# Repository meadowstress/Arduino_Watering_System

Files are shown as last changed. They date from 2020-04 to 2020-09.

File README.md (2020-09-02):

# Arduino_Watering_System

This repo was created for my own plant watering system on my balcony. The project has basically reached the development peak.
With the current ressources of an Arduino Uno further feature development is pretty limited. So in the future activities will
be limited. And if time allows I will spend my energy in better unit tests and refactoring work.

You'll find the website of this repository here: https://meadowstress.github.io/Arduino_Watering_System/

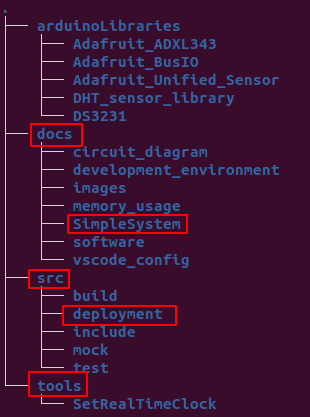
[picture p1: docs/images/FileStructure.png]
FileStructure


There are several folders in the repo. The most interesting for others is possibly the "src/deployment" folder. You can have a
look at the Arduino entry point in the "deployment.ino". All self written libraries are within the "deployment" folder.

If you want to recreate my plant watering system or parts of it you can have a look at the "doc" folder. In "circuit_diagram"
you find a Fritzing diagramm of my system. In "software" you'll find some useful tipps on how to handle the code.

If you just want to get started with programming an Arduino you'll find in docs/SimpleSystem a simplistic apporach including
system code and circuit diagramm to get started with an basic Arduino watering system.

All other folders are used for developing this project further and are possibly of minor interest to you:
The folder "src" contains the development code of my project including all unit tests. I use this folder to develop Arduino
code on my PC in order to speed up development. In "tools" you find scripts which are necessary in order to configure used
hardware parts.

## Overview

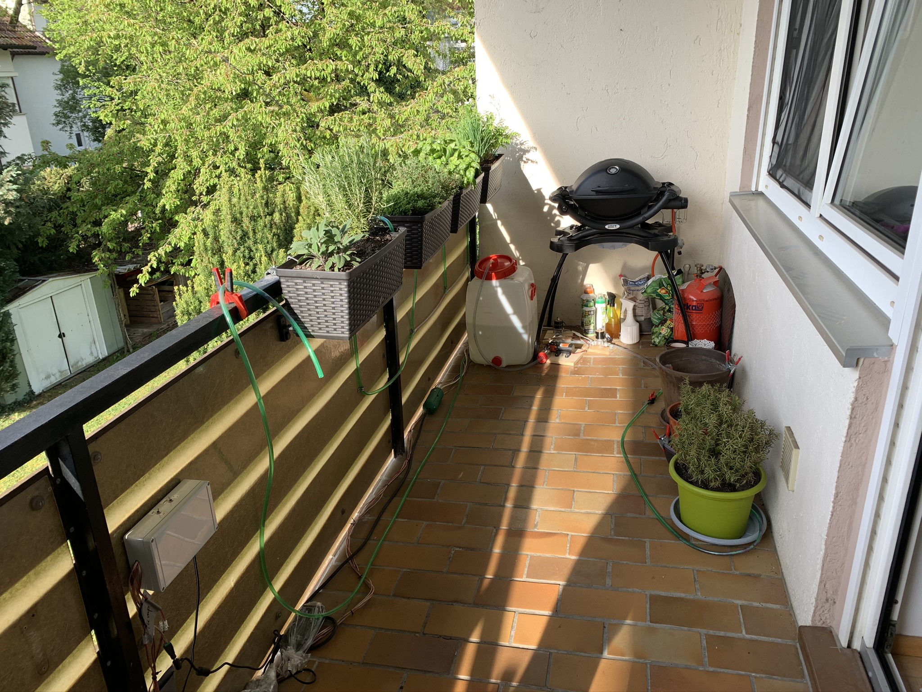
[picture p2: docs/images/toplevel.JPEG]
toplevel


### Control Box

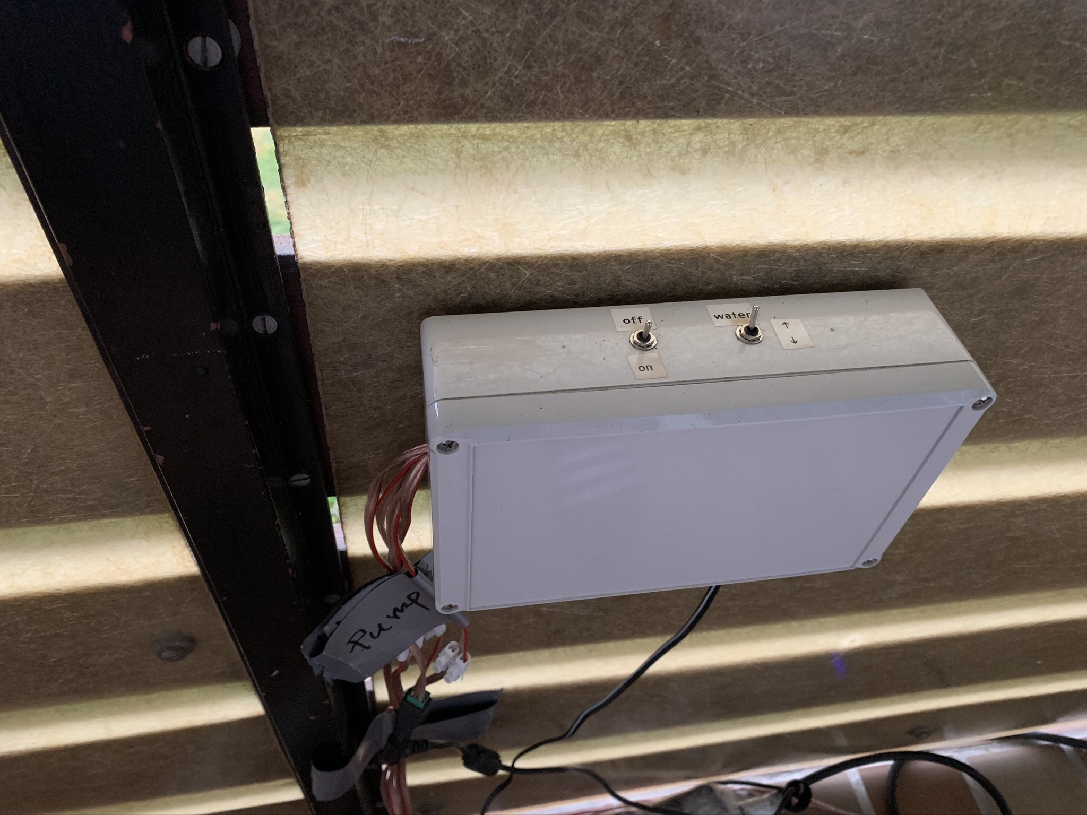
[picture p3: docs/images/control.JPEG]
control


## Pump and Valves

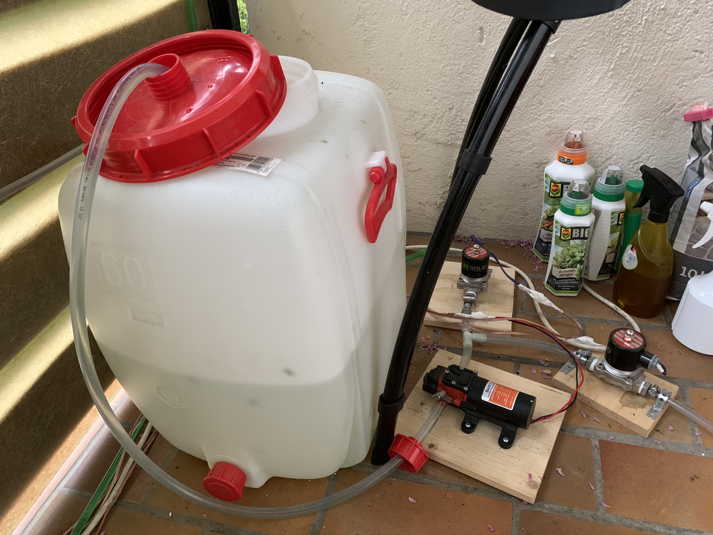
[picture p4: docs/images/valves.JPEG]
valves


## Tubes to top Plants

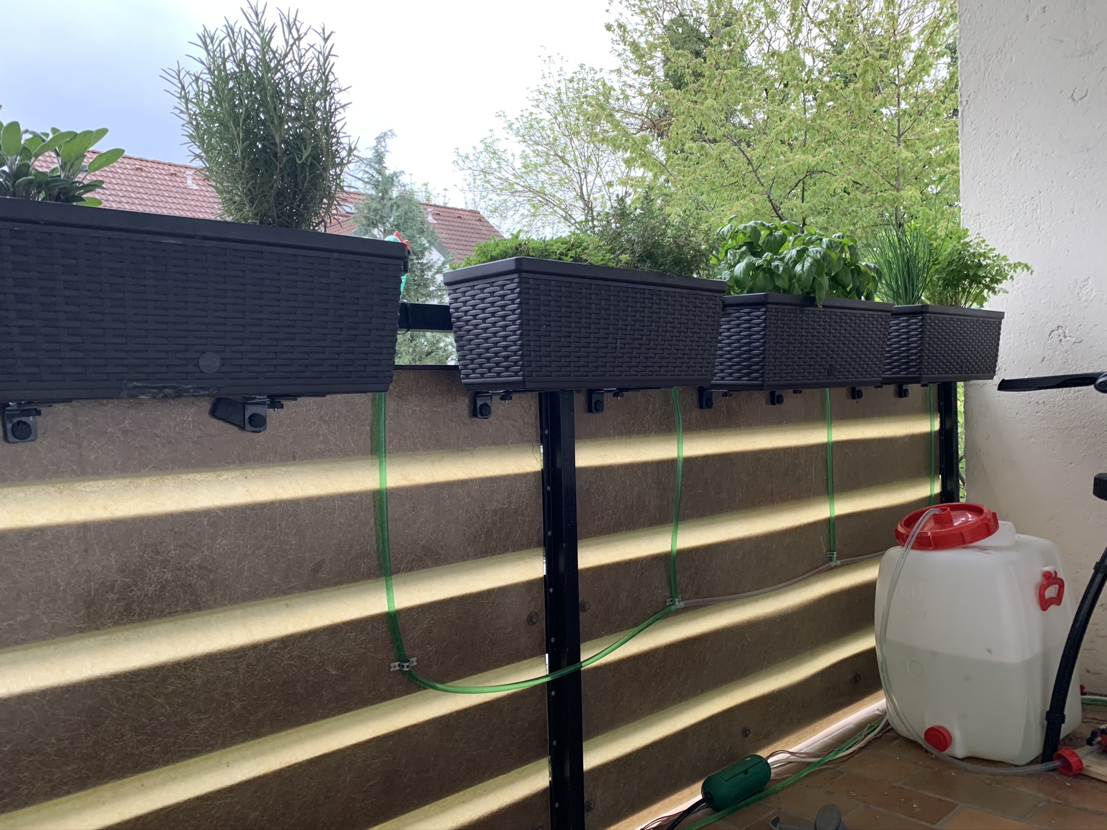
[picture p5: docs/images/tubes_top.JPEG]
tubes_top


## Tubes to bottom Plants

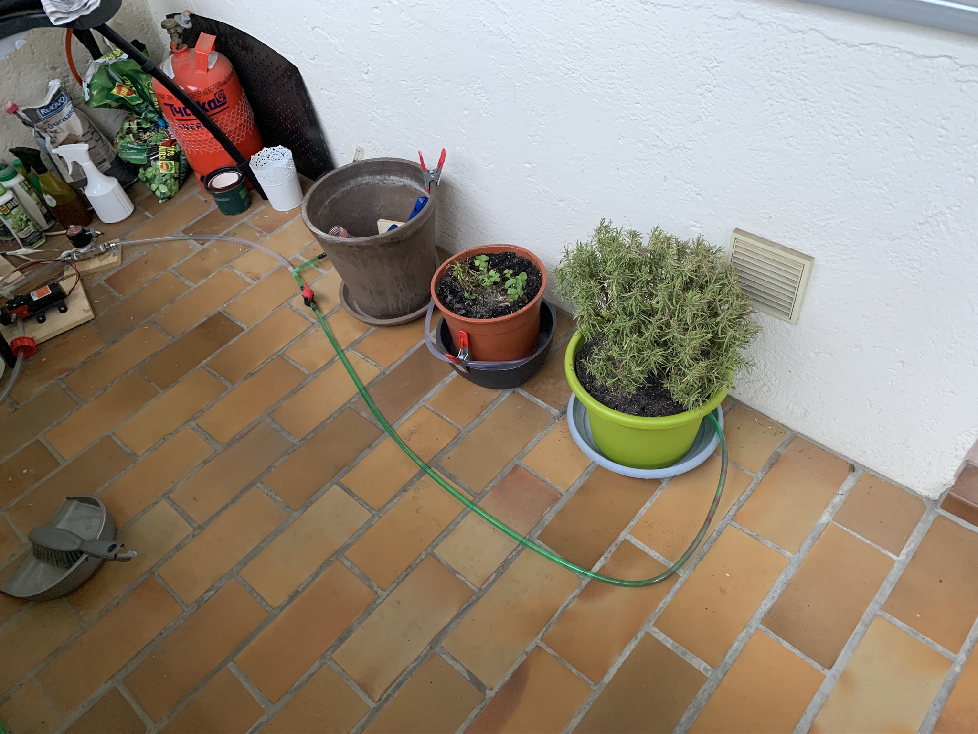
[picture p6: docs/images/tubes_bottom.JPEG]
tubes_bottom


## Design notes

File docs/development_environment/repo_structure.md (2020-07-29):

Repo Structure
==============

The build folder on top level is needed for the arduino build files and the build folder in src/build for cmake!

VSCode Configuration
====================

The build folder for the arduino has to be declared in the arduino.json configuration file.
The path to the arduino installation files has to be specified in the arduino settings or in the c_cpp_properties.json directly

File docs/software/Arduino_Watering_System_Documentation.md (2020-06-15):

Application Time Constants
==========================

For Temperatures around 30 degrees Celcius the following time constants should
be used:

Plants on top t = 40000 ms for 4 Plants
Plants on bottom t = 15000 ms for 2 Plants

At 30 Degrees a bazil plant in bare sun needs estimately 1.4 l of Water per
day which is a full plant can of mine.

Temperature Measurement

=======================

The thermometer measures estimately 10 degrees Celcius too much since it heatens
up in the sun. Due to that the usual reference temperature range is 35°C - 45°C
which you can find in the former Watering Time Constants below. Which is also
the Range where the application watering time constats are picked as well.

Former Watering Time Constants

==============================

//Watering parameters for top plants
const float maxTemp = 55.0F;
const unsigned int timeMaxTempTop = 60000;
const unsigned int timeMaxTempBottom = 20000;

const float temp2 = 45.0F;
const unsigned int timeTemp4Top = 40000;
const unsigned int timeTemp2Bottom = 15000;

const float temp3 = 35.0F;
const unsigned int timeTemp3Top = 30000;
const unsigned int timeTemp3Bottom = 10000;

const float temp4 = 25.0F;
const unsigned int timeTemp2Top = 20000;
const unsigned int timeTemp4Bottom = 8000;

const float lowTemp = 18.0F;
const unsigned int timeLowTempTop = 8000;
const unsigned int timeLowTempBottom = 4000;

//Water Times
const TIME t1_water(11, 30);
const TIME t2_water(15, 30);
const unsigned int t_valve = 100;
const unsigned int t_half_can = 15000;

Expectations for Unit Tests

===========================

The unit test expect the following point of times for watering:
11:30 Uhr and 15:30 Uhr otherwise the unit tests will fail.

Hardware Libraries

==================

The hardware Libraries for the DHT22 temperature sensor and the DS3231 real time
clock can be found in the library manager in the arduino development environ-
ment.

SD-Card Reader
==============

For preparing the SD card for the SD-Card reader follow the instructions found
here:

https://www.arduino.cc/en/Reference/SDCardNotes

Find the sdcard path to the drive with the command "df" in the shell.
Then in my case the command for formating the SD card with FAT32 is:

sudo mkdosfs -F 32 /dev/mmcblk0p1

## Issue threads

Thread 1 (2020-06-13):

Bug in successive minutes of watering

meadowstress, 2020-06-13:
expected behaviour: the watering will be triggered two times

actual behaviour: the watering is triggered multiple times

If successive minutes are set in the parameters e.g. 10:00 and 10:01 for watering then in the second minute the "timer_water_flag" is not set to true and in the second time of watering in this example at 10:01 the system will constantly trigger the watering for one minute.

meadowstress, 2020-07-28:
I updated today the internal time resolution to one second. This enables now subsequent watering times of one minute. So parameters of 10:00:00 and 10:01:00 would be now possible to configure. Constants of 10:00:00 and 10:00:01 would still cause an issue but this should not a practical used case since the watering process would usually take more than one second i.e. 1000 ms. So this issue can be closed now.

Closed 2020-07-28.

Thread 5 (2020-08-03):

Hold function needs to be cleaned

meadowstress, 2020-08-03:
The hold function has left overs from the water level detection feature which got deactivated due to malfunction. Either there needs to be a better solution implemented or the logic should be erased.

The main problem is that the water level detection needs to be switched on for every cycle of the hold function. This doesn't work properly. Probably because of inductivity and capacity of the cable, meaning there are electromagnetic waves created in the cable that probably are causing distortions. So the watering gets interrupted very soon because of distortion of the water level detection bit.

meadowstress, 2020-09-02:
Hold function refactored.

Closed 2020-09-02.

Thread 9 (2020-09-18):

refactor holdState function

meadowstress, 2020-09-18:
Function should return elapsed time to evaluate if the state was held for the whole time configured.

Function isSystemSwitchedOn() should be used to check for every loop cycle instead of switch_on variable to make code slimmer.

Maybe error logging in hold function should be rethought

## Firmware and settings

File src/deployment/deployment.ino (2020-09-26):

#include <Wire.h>  // Enable on Hardware

//#include "mock_arduino.h"  //Enable for testing
#include "mytime.h"
#include "PS_func.h"
#include "parameter.h"
#include <DS3231.h>  //Enable on Hardware

// global states of external devices
DS3231 clock_var;
RTCDateTime DateTime;
DHT dht(par::TEMPERATURE, DHT22);  // Enable for Hardware

// global system variable
WaterSystem PumpControl;
unsigned long global_counter = 0;  // counter for cycles

// int main(void)  // Enable for Testing
//{               // Enable for Testing

void setup()  // Enable on Hardware
{

    pinMode(par::PUMP, OUTPUT);         // Enable on Hardware
    pinMode(par::VALVETOP, OUTPUT);     // Enable on Hardware
    pinMode(par::VALVEBOTTOM, OUTPUT);  // Enable on Hardware
    pinMode(par::VALVETUBE, OUTPUT);    // Enable on Hardware
    pinMode(par::SWITCH, INPUT);        // Enable on Hardware
    pinMode(par::WATER, INPUT);         // Enable on Hardware
    pinMode(par::WATERLEVEL, INPUT);    // Enable on Hardware
    pinMode(par::LED, OUTPUT);          // Enable on Hardware

    Serial.begin(115200);  // Enable on Hardware

    dht.begin();                       // Enable on Hardware
    clock_var.begin();                 // Enable on Hardware
    pinMode(par::CHIPSELECT, OUTPUT);  // Enable on Hardware

    digitalWrite(par::PUMP, HIGH);         // default no pumping enabled
    digitalWrite(par::VALVETOP, HIGH);     // default no pumping enabled
    digitalWrite(par::VALVEBOTTOM, HIGH);  // default no pumping enabled
    digitalWrite(par::VALVETUBE, HIGH);    // default no pumping enabled
    digitalWrite(par::LED, LOW);           // default led off

    // prevent different states when water switch is on
    if (digitalRead(par::WATER) == LOW)
    {
        PumpControl.setPreStateWater(true);
        PumpControl.setCurrentStateWater(true);
    }

    Serial.println(F("\n\nStart of Program:"));
    Serial.println(F("-----------------\n"));

}  // Enable on Hardware

// for (int i = 0; i < 5; i++)  // enable for Testing
//{                            // enable for Testing

void loop()  // Enable on Hardware
{            // Enable on Hardware

    // Check if info should be logged
    logSystemInfo();

    // Check manual watering
    // applied only to valve for top plants since there is
    // the manual tube attached for which this feature is designed
    PumpControl.pumpWaterManual();

    // check automatic watering
    PumpControl.pumpWaterClock();

    // turn error led on or off
    PumpControl.checkSystem();
    //}  // Enable for Testing
}

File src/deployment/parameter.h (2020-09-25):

#ifndef PARAMETER_H
#define PARAMETER_H

#include "mytime.h"

namespace par
{

// pins
const byte PUMP        = A0;
const byte VALVETOP    = A1;
const byte VALVEBOTTOM = A2;
const byte VALVETUBE   = A3;
const byte SWITCH      = 7;
const byte WATER       = 3;
const byte WATERLEVEL  = 4;
const byte TEMPERATURE = 6;
const byte LED         = 8;

// SD-pins
const byte CHIPSELECT = 10;  // SD-Card Pin for Arduino Uno

// Watering parameters for top plants
const float maxTemp                  = 55.0F;
const unsigned int timeMaxTempTop    = 60000;
const unsigned int timeMaxTempBottom = 45000;

const float temp4                  = 45.0F;
const unsigned int timeTemp4Top    = 40000;
const unsigned int timeTemp4Bottom = 30000;

const float temp3                  = 35.0F;
const unsigned int timeTemp3Top    = 30000;
const unsigned int timeTemp3Bottom = 23000;

const float temp2                  = 25.0F;
const unsigned int timeTemp2Top    = 17000;
const unsigned int timeTemp2Bottom = 13000;

const float lowTemp                  = 20.0F;
const unsigned int timeLowTempTop    = 8000;
const unsigned int timeLowTempBottom = 6000;

// Water Times
const TIME t1_water(11, 30, 0);
const TIME t2_water(15, 30, 0);
const byte t_valve            = 100;
const unsigned int t_half_can = 15000;
}  // namespace par

#endif

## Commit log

2019-09-09 Initial commit for Arduino automatic plant watering system
2019-09-13 Bug fixes water level feature and cleanup of master branch in build folder
    [Arduino_PS.cpp, PS_func.cpp]
2019-09-14 Prepare deployment to Arduino
2019-09-21 Add contition to function Pump_Water for writing output pins
2019-09-21 Adaption to pulldown resistors with switches implemented
2019-09-21 Adapt mocking tests to inverted defintion of HIGH==true and LOW==false
    [test_mocks.cpp]
2019-09-21 Adapt comment for mocking issues of LOW and HIGH
    [mock_arduino.cpp]
2019-09-23 Refactor Pump_Water_Clock function to class and get rid of globals by adding them as class members
2019-10-08 Refactor Code to use external pullup resistors
2019-10-14 Mock external temperature sensor for software
2019-10-15 Implement basic feature of temperature measurement and make software ready for deployment
2019-10-17 Implement temperature dependend watering feature
2019-10-17 Refactor Pump_Water_Clock method to generate watering times out of temperatures
2019-10-18 Add prints to method Pump_Water_Clock for debugging and refactoring
2019-10-18 Prepare deployment for temperature feature and edit mock_arduino.cpp
2019-10-18 Add parameter file for temperature feature
2019-10-18 Prepare software for deployment and add monitoring of temperature to serial monitor
2019-10-19 Change display intervall of temperature to 1 min
2019-10-25 Implement mock for external system clock and prepare pump timer function
2019-10-27 Change input mode for pins with external pullup resistors
2019-10-27 Quick fix for bug regarding multiple watering in one minute due to low time resolution
    [Arduino_PS.cpp]
2020-04-03 Add comments to current main for documentation
2020-04-06 Preparation for Deployment: Add Handling for external Clock Device
2020-04-10 Preparing Software for Release
    * external real time clock
    * temperature measurement
    * enable automatic watering at 11:30 and 15:30
    * adapting time constants for bottom plants
    (only half of the time since there is only
    one plant instead of two)
    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
2020-04-10 Print relevant Information to Serial Monitor
    * Current Time
    * Current Temperature
    * Current Watering Time Constants
    * At Watering:
    - Date
    - Time
    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
2020-04-10 Temperature Range to Serial Monitor Info
    This patch adds the current selected temperature
    range and the chosen ms for watering the top plants
    to the cyclic printed information on the serial monitor.
2020-04-19 Add printCyclicSystemInfo function
    * add support function
    * make main function slimmer
    * encapuslate code
2020-04-19 Refactor main function
    * outsource pin parameters to parameter.h
2020-04-19 Rename time parameters of system * temperature 4 is now greater than temperature 3 * temperature 3 is now greater than temperature 2
2020-04-20 Refactor Unit Tests
    * restructure test files and folders
    * start rewriting tests with test Fixtures and Parameters
    * restructure CMakeLists.txt
    * restructure google test main
    [Arduino_PS.cpp, PS_func.cpp, mock_arduino.cpp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]
2020-04-21 Refactor Unit Tests
    * Introduce parameterized tests
    * use test fixtures
    [test_WaterSystem.h]
2020-04-27 Add circuit documentation to project
    * add fritzing diagram
    * add downloaded parts
    [Arduino_Pump_Control.fzz]
2020-04-27 Adapt circuit diagram
    [Arduino_Pump_Control.fzz]
2020-04-27 Update circuit diagramm
    [Arduino_Pump_Control.fzz]
2020-04-28 Adapt documentation
    * adapt fritzing diagram
    * add pictures to readme file
    [Arduino_Pump_Control.fzz]
2020-04-29 Adapt parameter file
    * decrease water time for bottom plants due to fewer consumption
    * increase temperature for watering to avoid waterlogging
    [parameter.h]
2020-06-07 Prepare System for SD Card Reader
    [Arduino_Pump_Control.fzz]
2020-06-12 Add initial SD fuctionality
    * add methods for writing on SD card
    * add necessary Arduino Libraries to repo
2020-06-12 Fix global system variable bug
    [deployment.ino]
2020-06-13 Reduce dynamic memory usage
    * dynamic memory usage about 95% had to be reduced
    * reduction reached by using data type byte and
    function F() with Serial.println() which stores
    all string that are used to print on the serial
    monitor to the flash memory
    * reduction from 95% to 57% dynamic memory reached
    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
2020-06-13 Add SD print/log functionality to code
2020-06-13 Fix format issues with logging
    [PS_func.cpp, time.cpp]
2020-06-17 Limit logging only to watering
    * introduce logging function
    * change symbol of system print function
2020-06-17 Fix loggin of water time parameters
    * no cyclic data written to SD card
    * only relevant data logged
    * logfile size reduced
    [PS_func.cpp, time.cpp]
2020-06-18 Fix delay for manual watering
    [Arduino_PS.cpp, PS_func.cpp, deployment.ino]
2020-06-18 Fix bug that disables automatic watering
    * timer_water_flag unintendedly set to false
    [Arduino_PS.cpp, deployment.ino]
2020-06-18 Fix loggin issue with manual watering
    [Arduino_PS.cpp, PS_func.cpp, deployment.ino]
2020-06-18 Fix output on serial monitor for manual watering
    [PS_func.cpp]
2020-06-19 Add print finish SD writing message to Serial output
2020-07-28 Fix bugs in printing and logging parameters
    [Arduino_PS.cpp, PS_func.cpp, deployment.ino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]
2020-07-29 Add VSCode arduino flashing configuration to repo
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2020-07-29 Fix issue of multiple logging within one second and rename function symbol
    [Arduino_PS.cpp, PS_func.cpp, deployment.ino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]
2020-07-31 Cleanup of Code * remove isWaterLevelOk() from pumpWaterClock() * change baud rate to VSCode standard baud rate * change pin state of MEASURE_WL pin
2020-08-01 Fix bug of watering interruption
    * disable water level detection while hold_state function
    * add logging of failure when water level detection feature detects no water
    [PS_func.cpp]
2020-08-03 Add message to serial monitor for insufficient water level * pumpWater, holdState
2020-08-13 Introduce Water Level Sensor to the Code
    * delete old logic with measuring via cable
    * reactivate water level check while hold function (watering)
2020-08-16 Add water level check to pumpWaterManual and pumpWaterClock functions
2020-08-18 Fix Bug in isAutomaticWateringEnabled function
    * replace hardcoded threshold by parameter
    [PS_func.cpp]
2020-08-18 Refactor pumpWaterClock function
    * log system data every time the watering parameter time is reached
    * consistently use variabels for watering check
    * add error message for disabled watering due to low temperature
    [PS_func.cpp]
2020-08-19 Add message to pumpWaterClock function for system switched off
2020-08-19 Add unexpected error to pumpWaterClock function
    [PS_func.cpp]
2020-08-21 Adapt failing unit tests to current code
    [mock_arduino.cpp, mocks_test.cpp]
2020-08-21 Add fourth relay to Arduino for water tube
2020-08-23 Fix Bug of undefined state of valve pin for water tube
    [Arduino_PS.cpp, deployment.ino]
2020-08-27 update circuit wire diagramm (fritzing)
    * adding 3rd valve for water tube
    * adding water level sensor
    * adding sd card reader
    [Arduino_Pump_Control.fzz]
2020-08-28 Update Documentation
    * add SimpleSystem sketch
    * add SimpleSystem fritzing sketch
    * update readme file
    [SimpleSystemCircuit.fzz]
2020-09-02 Refactor code functions and prepare for deployment
    * HoldState
    * PumpWater
    * fix HoldStateWater test and the HoldState function
    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
    [PS_func.cpp]
2020-09-14 Remove global Object PumpControl from member functions of WaterSystem class
2020-09-16 Add led feedback signal to water system
    * add system_ok to WaterSystem class
    * add checkSystem() method to WaterSystem class
    * add pin::LED to parameters
2020-09-16 Fix bug for wrong output voltage of led pin
    * congfigure led pin properly as output
    * full voltage of 5V is then at led pin
    [Arduino_PS.cpp, deployment.ino]
2020-09-17 Add log entry for interuption of holdState function * by on off switch
2020-09-17 Fix bug of water switch
    * no proper initialisation of water switch
    * issue appeared due to move of global variables to WaterSystem class
    [deployment.ino]
2020-09-26 Copy replace arduino sketch by test main to avoid further bugs
    [deployment.ino]
